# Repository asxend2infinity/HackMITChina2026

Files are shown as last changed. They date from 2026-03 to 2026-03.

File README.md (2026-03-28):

# HackMITChina2026  
**AeroVis – Helmet Integrated Heads-Up Display for Time Trial Cycling**
**Rigonomics – Real-time Riding Posture Adjustment Algorithm**

---

**Overview**

AeroVis is a helmet-integrated heads-up display (HUD) system designed for the Giro Aerohead II TT helmet, enabling cyclists to view real-time performance data without breaking their aerodynamic position.

In time trial cycling, even small posture changes can significantly impact performance. AeroVis eliminates the need to look down at a cycling computer by placing critical data directly within the rider’s field of view.

As for Rigonomics: the majority of cyclists lack professional fitting advice, and ride in over-agressive or other non-optimal postures. Rigonomics provides real-time posture adjustment advices to riders through Aerovis. By calculating critical angles used by professional fitters during fitting and bike adjustments using body-mounted gyroscopes, it can notify cyclists when their knee joints are over straight, arms are over/under streached, or leaning too forward/backward. 

This helps amature cyclists prevent injuries due to incorrect cycling postures and professional cyclists maintain efficient riding postures (improve performance).

---

**Key Features**

- Real-time display of cycling metrics (speed, power, cadence, etc.)
- Maintains full aerodynamic riding posture
- Minimal, non-intrusive UI designed for safety and clarity
- Lightweight, helmet-integrated hardware design
- Expandable architecture for future algorithm integration
- Posture alert

---

**System Architecture**

The system consists of three main components:

**Embedded System (ESP32)**  
- Handles data processing and communication  
- Receives sensor or external cycling data  
- Drives the display output  

**Display Module (HUD)**  
- Uses 2 0.91" OLED screens to reflect data onto the helmet visor  
- Optimized for visibility and minimal obstruction  

**Mechanical Integration**  
- Custom-designed housing for Giro Aerohead II TT helmet  
- Designed to intergrate the AeroVis system without altering the structure of the helmet  

**WIT Bluetooth 5.0 Giroscope module**  
- Integrated gyroscope solution with Bluetooth broadcast and built-in battery.

---

**Tech Stack**

- Microcontroller: ESP32 Dev Kit  
- WIT Bluetooth 5.0 giroscope module
- Development Environment: VSCode + PlatformIO  
- CAD Design: SolidWorks  
- Programming Language: C/C++ (embedded)  
- Prototyping Support: ChatGPT-assisted rapid development  

---

**How It Works**

Aerovis:
1. The ESP32 receives cycling data (bluetooth).  
2. Data is processed and formatted for display.  
3. The HUD renders key metrics in real time.  
4. The rider views information without needing to look down.  

Rigonomics:
1. Giro data is sent to ESP32
2. Data is processed and determinant angles are calculated
3. Alerts are displayed when rider posture crosses critical thresholds

---

**Hardware Setup**

- ESP32 & custom PCB (file included)
- OLED screens (Listed in BOM)
- Power source (Listed in BOM)  
- Custom 3D-printed mount (SolidWorks file included)  
- Giro Aerohead II MIPS

**Note:** Exact pin configuration might depend on the display module used.

---

**Getting Started**

1. Order PCB & components according to BOM, 3D print housing  
2. Clone the Repository  
3. Open in PlatformIO  

Open the project folder in VSCode  

Ensure PlatformIO extension is installed  

For pairing: Run scan_util.py and open local webpage using a browser

4. Build & Upload  

Connect ESP32 via USB  

Select correct COM port  

Upload firmware:

```bash
pio run --target upload
```

---

**Challenges**

- Maintaining visibility without obstructing rider vision  
- Integrating electronics within structural constraints  
- Ensing stable real-time data transmission  
- Angle calculation and WIT sensor connection & data decode

---

**What We’re Proud Of**

- Functional AeroVis prototype, and partially functioning Rigonomics algorithm combining hardware + embedded systems  
- Practical application in both professional and amature cycling  
- Clean integration into an existing aerodynamic helmet design  
- Strong foundation for future algorithms and extended functions

---

**Contributors**

AeroVis/Rigonomics: Pinchen LIN
Pairing Utility: Shiting HUANG

**UNRESOLVED ISSUES**

New firmware has occasional issues connecting to cycling sensors, for stable pure info display functions use aerovis_1.0_firmware.cpp in Legacy code as main.cpp; WIT motion sensors also seem to incorrectly calibrated each time rebooting, leading to inconsistent alerts and potential false alarms without manual calibration. Both issues are under investigation

**NEW FUNCTIONS**

Developed during HackMIT China 2026: New firmware adds support for Rigonomics: an algorithm designed to give rider posture adjustment alerts based on gyroscope data. Sensors can now also be added through an HTML+python utility, so users do not need to change source code when pairing new sensors. NEW PARING ROUTINE: Use scan_util to update sensor_addresses.txt, and re-upload via PIO

**FUTURE WORK**
 - Might add different UI layouts to display specialized info
 - Companion firmware site under development: settings will be adjustable without having to install PIO, VSCode .etc
 - Optical/visual enhancements

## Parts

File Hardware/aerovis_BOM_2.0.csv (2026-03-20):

No. | Quantity | Comment | Designator | Footprint | Value | Manufacturer Part | Manufacturer | Supplier Part | Supplier
1 | 4 | 100nF | C1,C10,C11,C13 | C0603 | 100nF | 0805B104K500NT | FH(风华) | C38141 | LCSC
2 | 1 | 10uF | C2 | C0603 | 10uF | CL21A106KOQNNNE | SAMSUNG(三星) | C1713 | LCSC
3 | 3 | 1uF | C3,C14,C15 | C0603 | 1uF | CL21B105KBFNNNE | SAMSUNG(三星) | C28323 | LCSC
4 | 6 | 4.7uF | C5,C42,C44,C46,C49,C50 | C0603 | 4.7uF
5 | 2 | 2.2uF | C6,C52 | C0603 | 2.2uF
6 | 2 | 10uF | C7,C8 | CAP-SMD_L3.2-W1.6-RD-C7171 | 10uF | TAJA106K016RNJ | Kyocera AVX | C7171 | LCSC
7 | 3 | 22uF | C34,C35,C36 | C0603 | 22uF
8 | 2 | 22uf | C37,C38 | C0603 | 22uf
9 | 4 | 1uF | C39,C40,C45,C47 | C0603 | 1uF
10 | 4 | 0.1uF | C41,C43,C48,C51 | C0603 | 0.1uF
11 | 2 | 10uf | C53,C54 | C0603 | 10uf | CGA0603X7R104K500JT | HRE(芯声) |  | LCSC
12 | 2 | 1N4148W | D1,D2 | SOD-123_L2.7-W1.6-LS3.7-FD |  | 1N4148W | R+O(宏嘉诚) | C7420318 | LCSC
13 | 2 | X6511WV-22H-C30D60 | H4,H5 | HDR-TH_22P-P2.54-V-M |  | X6511WV-22H-C30D60 | XKB Connectivity(中国星坤) | C725954 | LCSC
14 | 1 | 1uH | L1 | IND-SMD_L4.4-W4.2 | 1uH
15 | 1 | XL-5050RGBC-WS2812B | LED1 | LED-SMD_4P-L5.0-W5.0-BL_XL-5050RGBC |  | XL-5050RGBC-WS2812B | XINGLIGHT(成兴光) | C2843785 | LCSC
16 | 2 | SZYY0805B | LED3,LED4 | LED_0603 |  | SZYY0805B | yongyu(永裕光电) | C434433 | LCSC
17 | 1 | LED_0603-R | LED5 | LED_0603
18 | 2 | SS8050-G | Q1,Q2 | SOT-23-3_L2.9-W1.6-P1.90-LS2.8-BR |  | SS8050-G | CJ(江苏长电/长晶) | C164886 | LCSC
19 | 2 | 10kΩ | R1,R2 | R0603 | 10kΩ | 0805W8F1002T5E | UNI-ROYAL(厚声) | C17414 | LCSC
20 | 1 | 10kΩ | R3 | R0603_NEW | 10kΩ | 0805W8F1002T5E | UNI-ROYAL(厚声) | C17414 | LCSC
21 | 2 | 5.1kΩ | R5,R6 | R0603 | 5.1kΩ
22 | 2 | 1kΩ | R10,R11 | R0603 | 1kΩ | RC0805FR-071KL | YAGEO(国巨) | C95781 | LCSC
23 | 6 | 4.7K | R20,R21,R22,R24,R26,R27 | R0603 | 4.7K
24 | 2 | 560K | R23,R25 | R0603 | 560K
25 | 1 | 1K | R28 | R0603 | 1K
26 | 1 | 0.5Ω | R30 | R0603 | 0.5Ω
27 | 1 | 10K | R31 | R0603 | 10K
28 | 1 | 2Ω | R35 | R0603 | 2Ω
29 | 2 | SKRPACE010 | SW1,SW2 | KEY-SMD_4P-L4.2-W3.2-P2.20-LS4.6 |  | SKRPACE010 | ALPSALPINE(阿尔卑斯阿尔派) | C139797 | LCSC
30 | 1 | TS-1101VS-B-A-A | SW3 | SW-SMD_TS-1101VS-C-A-B |  | TS-1101VS-B-A-A | XKB Connection(中国星坤) | C561499 | LCSC
31 | 2 | Test-Point | TP1,TP2 | Test-Point-0.5mm
32 | 1 | ESP32-S3-WROOM-1-N16R8 | U1 | WIRELM-SMD_ESP32-S3-WROOM-1 |  | ESP32-S3-WROOM-1-N16R8 | ESPRESSIF(乐鑫) | C2913202 | LCSC
33 | 1 | AMS1117-3.3 | U3 | SOT-223-4_L6.5-W3.5-P2.30-LS7.0-BR |  | AMS1117-3.3 | UMW(广东友台半导体) | C347222 | LCSC
34 | 1 | CH343K | U4 | ESSOP-10_L4.9-W3.9-P1.0-LS6.0-TL-EP |  | CH343K | WCH(南京沁恒) | C5832295 | LCSC
35 | 2 | HC-FPC-0.5-14P-FH20 | U7,U8 | FPC-SMD_14P-P0.50_HC-FPC-0.5-14P-FH20 |  | HC-FPC-0.5-14P-FH20 | HC(虹成电子) | C19273929 | LCSC
36 | 1 | IP5306 | U10 | ESOP-8_L4.9-W3.9-P1.27-LS6.0-BL-EP |  | IP5306 | INJOINIC(英集芯) | C181692 | LCSC
37 | 2 | 662K | U12,U13 | SOT-23-3_L2.9-W1.3-P1.90-LS2.4-BR |  | 662K | HXY MOSFET(华轩阳电子) | C7470756 | LCSC
38 | 1 | KH-TYPE-C-16P | USB1 | USB-C-SMD_KH-TYPE-C-16P |  | KH-TYPE-C-16P | kinghelm(金航标) | C709357 | LCSC

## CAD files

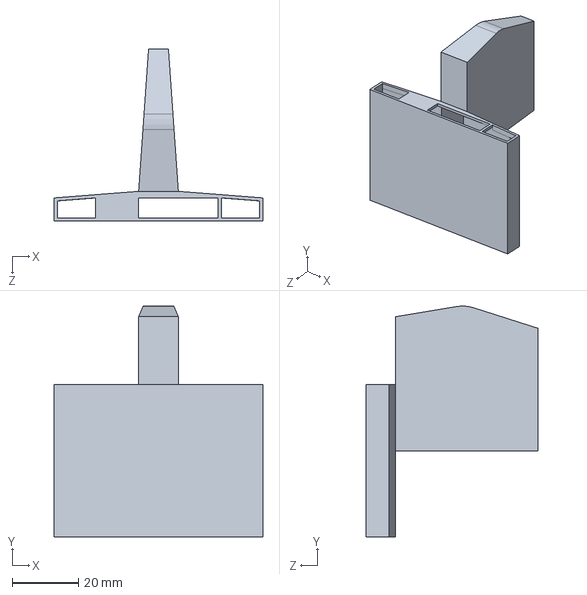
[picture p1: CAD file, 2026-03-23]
Hardware/aerovis_housing_3.0.SLDPRT
63.0 x 69.7 x 52.0 mm

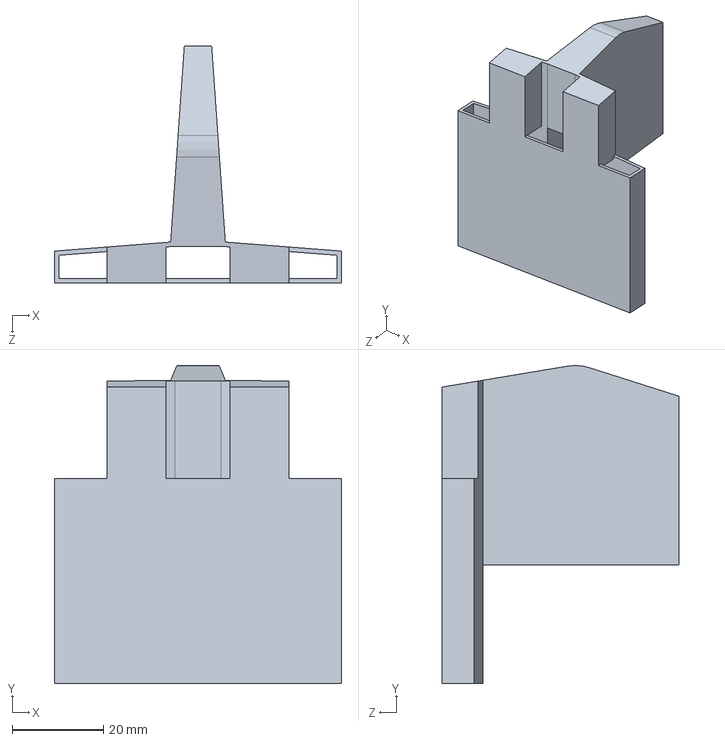
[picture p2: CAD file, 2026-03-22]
Hardware/aerovis_housing_2.0.SLDPRT
63.0 x 69.7 x 52.0 mm

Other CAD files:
Hardware/aerovis_housing_2.0.STL
Hardware/aerovis_housing_3.0.STL

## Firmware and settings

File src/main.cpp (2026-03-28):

#include <Arduino.h>
#include <Wire.h>
#include <SPIFFS.h>
#include <U8g2lib.h>
#include <NimBLEDevice.h>
#include <math.h>

// =======================================================
// OLEDs
// Screen 1: HW I2C SDA=8, SCL=9
// Screen 2: SW I2C SDA=6, SCL=7
// =======================================================
static const uint8_t OLED_ADDR_7BIT = 0x3C;

U8G2_SSD1306_128X32_UNIVISION_F_HW_I2C u8g2_screen1(U8G2_R0, U8X8_PIN_NONE);

U8G2_SSD1306_128X32_UNIVISION_F_SW_I2C u8g2_screen2(
    U8G2_R2,
    /* clock=*/7,
    /* data=*/6,
    /* reset=*/U8X8_PIN_NONE
);

// =======================================================
// Config file
// =======================================================
static const char* SENSOR_CONFIG_FILE = "/sensor_addresses.txt";

// =======================================================
// framebuffer horizontal mirror helpers
// =======================================================
static inline void mirrorHorizU8g2(U8G2 &u) {
    uint8_t *buf = u.getBufferPtr();
    const int w = u.getDisplayWidth();
    const int h = u.getDisplayHeight();
    const int pages = h / 8;

    for (int p = 0; p < pages; ++p) {
        int row = p * w;
        for (int x = 0; x < w / 2; ++x) {
            uint8_t tmp = buf[row + x];
            buf[row + x] = buf[row + (w - 1 - x)];
            buf[row + (w - 1 - x)] = tmp;
        }
    }
}

static inline void sendBufferMirrored(U8G2 &u) {
    mirrorHorizU8g2(u);
    u.sendBuffer();
    mirrorHorizU8g2(u);
}

// =======================================================
// Cycling HUD values
// =======================================================
String spdVal  = "0.0";
String distVal = "0.00";
String gearVal = "N/A";

String hrVal   = "N/A";
String cadVal  = "N/A";
String pwrVal  = "N/A";

volatile float totalDist_km = 0.0f;

unsigned long lastSpeedUpdate = 0;
unsigned long lastGearUpdate  = 0;
unsigned long lastHrUpdate    = 0;
unsigned long lastCadUpdate   = 0;
unsigned long lastPwrUpdate   = 0;

const unsigned long TIMEOUT_MS = 2000;

// =======================================================
// Cycling BLE constants/devices
// =======================================================
static const char* DI2_SVC_UUID   = "000018ef-5348-494d-414e-4f5f424c4500";
static const char* DI2_CHAR_UUID  = "00002ac1-5348-494d-414e-4f5f424c4500";

NimBLEAdvertisedDevice* di2Device = nullptr;
NimBLEClient*           di2Client = nullptr;

uint8_t lastGearPayload[32];
size_t  lastGearLen = 0;
bool    hasLastGear = false;

NimBLEAdvertisedDevice* hrDevice = nullptr;
NimBLEClient*           hrClient = nullptr;

NimBLEAdvertisedDevice* cadDevice = nullptr;
NimBLEClient*           cadClient = nullptr;

bool     hasLastCrank   = false;
uint16_t lastCrankRevs  = 0;
uint16_t lastCrankTime  = 0;

NimBLEAdvertisedDevice* spdDevice = nullptr;
NimBLEClient*           spdClient = nullptr;

bool     hasLastWheel   = false;
uint32_t lastWheelRevs  = 0;
uint16_t lastWheelTime  = 0;

NimBLEAdvertisedDevice* pmDevice = nullptr;
NimBLEClient*           pmClient = nullptr;

static const float WHEEL_CIRCUM_MM = 2105.0f;

// =======================================================
// Address targets loaded from config file
// =======================================================
String witTargetAddr[4];
String hrTargetAddr  = "";
String cadTargetAddr = "";
String spdTargetAddr = "";
String pwrTargetAddr = "";
String di2TargetAddr = "";

// =======================================================
// WIT BLE
// =======================================================
static const char* WIT_SERVICE_UUID = "0000ffe5-0000-1000-8000-00805f9a34fb";
static const char* WIT_NOTIFY_UUID  = "0000ffe4-0000-1000-8000-00805f9a34fb";

static const uint32_t WIT_DATA_TIMEOUT_MS = 2000;
static const uint32_t WIT_RETRY_PERIOD_MS = 3000;
static const uint32_t WIT_CONNECT_GAP_MS  = 300;

// =======================================================
// WIT sensor state
// Mapping:
// S1 = thigh
// S2 = calf
// S3 = arm
// S4 = back
// All use X angles
// =======================================================
struct SensorSlot {
    String targetAddr;
    NimBLEClient* client;
    float xAngle;
    float yAngle;
    uint32_t lastUpdate;
    String status;
};

SensorSlot sensors[4];

// =======================================================
// Posture parameters
// Formulas:
// knee = 180 + S2 - S1
// body = 180 - S1 + S4
// arm  = S3 - S4
// =======================================================
float KNEE_MAX_ALLOWED       = 150.0f;
float BODY_THIGH_MIN_ALLOWED = 70.0f;
float BODY_THIGH_MAX_ALLOWED = 110.0f;
float ARM_BODY_MIN_ALLOWED   = 75.0f;
float ARM_BODY_MAX_ALLOWED   = 95.0f;

// =======================================================
// Warning messages
// =======================================================
const char* MSG_KNEE_TOO_STRAIGHT = "KNEE TOO STRAIGHT";
const char* MSG_LEAN_FORWARD      = "LEAN FORWARD";
const char* MSG_LEAN_BACK         = "LEAN BACK";
const char* MSG_TUCK_ARMS_IN      = "TUCK ARMS IN";
const char* MSG_REACH_OUT         = "REACH OUT";

// =======================================================
// Posture / alert state
// =======================================================
String postureMessage = "";
String lastPostureMessage = "";
bool postureAlertActive = false;
uint32_t postureAlertLastSeenMs = 0;
static const uint32_t POSTURE_ALERT_HOLD_MS = 1200;

// Derived angles
float kneeAngle = 0.0f;
float bodyThighAngle = 0.0f;
float armBodyAngle = 0.0f;

// =======================================================
// Serial state cache
// =======================================================
String lastPrintedWitStatus[4];
bool lastPrintedDi2Connected = false;
bool lastPrintedHrConnected  = false;
bool lastPrintedCadConnected = false;
bool lastPrintedSpdConnected = false;
bool lastPrintedPwrConnected = false;
String lastPrintedAlert = "";
uint32_t lastPeriodicStatusMs = 0;

// =======================================================
// Forward declarations for WIT notify callbacks
// =======================================================
void notify0(NimBLERemoteCharacteristic*, uint8_t*, size_t, bool);
void notify1(NimBLERemoteCharacteristic*, uint8_t*, size_t, bool);
void notify2(NimBLERemoteCharacteristic*, uint8_t*, size_t, bool);
void notify3(NimBLERemoteCharacteristic*, uint8_t*, size_t, bool);

// =======================================================
// Helpers
// =======================================================
static inline bool di2Connected() { return di2Client && di2Client->isConnected(); }
static inline bool hrConnected()  { return hrClient  && hrClient->isConnected(); }
static inline bool cadConnected() { return cadClient && cadClient->isConnected(); }
static inline bool spdConnected() { return spdClient && spdClient->isConnected(); }
static inline bool pwrConnected() { return pmClient  && pmClient->isConnected(); }

static String normalizeAddr(const String& s) {
    String t = s;
    t.trim();
    t.toLowerCase();
    return t;
}

static bool witConnected(int idx) {
    return sensors[idx].client && sensors[idx].client->isConnected();
}

static bool witFresh(int idx) {
    return witConnected(idx) && (millis() - sensors[idx].lastUpdate <= WIT_DATA_TIMEOUT_MS);
}

static String decodeGear(const uint8_t* data, size_t len) {
    if (len < 6) return "N/A";
    uint8_t front = data[3];
    uint8_t rear  = data[5];
    if (front < 1 || front > 2) return "N/A";
    if (rear  < 1 || rear  > 12) return "N/A";
    return String(front) + "/" + String(rear);
}

static void printBanner(const char* title) {
    Serial.println();
    Serial.println("==================================================");
    Serial.println(title);
    Serial.println("==================================================");
}

static float wrap360(float a) {
    while (a >= 360.0f) a -= 360.0f;
    while (a < 0.0f) a += 360.0f;
    return a;
}

static float wrap180Signed(float a) {
    while (a > 180.0f) a -= 360.0f;
    while (a <= -180.0f) a += 360.0f;
    return a;
}

static float sensorAxisDeg(int idx) {
    return sensors[idx].xAngle;
}

static void setPostureAlert(const String& msg) {
    postureAlertActive = true;
    postureMessage = msg;
    lastPostureMessage = msg;
    postureAlertLastSeenMs = millis();
}

// =======================================================
// Cleanup helpers
// =======================================================
static void cleanupDi2Client() {
    if (di2Client) {
        if (di2Client->isConnected()) di2Client->disconnect();
        NimBLEDevice::deleteClient(di2Client);
        di2Client = nullptr;
    }
}

static void cleanupHRClient() {
    if (hrClient) {
        if (hrClient->isConnected()) hrClient->disconnect();
        NimBLEDevice::deleteClient(hrClient);
        hrClient = nullptr;
    }
}

static void cleanupCadClient() {
    if (cadClient) {
        if (cadClient->isConnected()) cadClient->disconnect();
        NimBLEDevice::deleteClient(cadClient);
        cadClient = nullptr;
    }
}

static void cleanupSpdClient() {
    if (spdClient) {
        if (spdClient->isConnected()) spdClient->disconnect();
        NimBLEDevice::deleteClient(spdClient);
        spdClient = nullptr;
    }
}

static void cleanupPwrClient() {
    if (pmClient) {
        if (pmClient->isConnected()) pmClient->disconnect();
        NimBLEDevice::deleteClient(pmClient);
        pmClient = nullptr;
    }
}

static void cleanupWitClient(int idx) {
    if (sensors[idx].client) {
        if (sensors[idx].client->isConnected()) sensors[idx].client->disconnect();
        NimBLEDevice::deleteClient(sensors[idx].client);
        sensors[idx].client = nullptr;
    }
}

// =======================================================
// HUD text helpers
// =======================================================
static const uint8_t X1 = 0;
static const uint8_t X2 = 44;
static const uint8_t X3 = 88;

static const uint8_t Y_HDR = 18;
static const uint8_t Y_VAL = 31;
static const uint8_t Y2_HDR = 13;
static const uint8_t Y2_VAL = 26;

static String fmtSPD()  { return spdConnected() ? (spdVal + "kph") : String("N/A"); }
static String fmtDIST() { return distVal; }
static String fmtGEAR() { return (di2Connected() && hasLastGear) ? gearVal : String("N/A"); }

static String fmtHR()   { return hrConnected()  ? hrVal  : String("N/A"); }
static String fmtCAD()  { return cadConnected() ? cadVal : String("N/A"); }
static String fmtPWR()  { return pwrConnected() ? pwrVal : String("N/A"); }

// =======================================================
// Serial reporting
// =======================================================
static void printCyclingConnStatus() {
    bool di2 = di2Connected();
    bool hr  = hrConnected();
    bool cad = cadConnected();
    bool spd = spdConnected();
    bool pwr = pwrConnected();

    if (di2 != lastPrintedDi2Connected) {
        Serial.print("[HUD] DI2: ");
        Serial.println(di2 ? "CONNECTED" : "DISCONNECTED");
        lastPrintedDi2Connected = di2;
    }
    if (hr != lastPrintedHrConnected) {
        Serial.print("[HUD] HR: ");
        Serial.println(hr ? "CONNECTED" : "DISCONNECTED");
        lastPrintedHrConnected = hr;
    }
    if (cad != lastPrintedCadConnected) {
        Serial.print("[HUD] CAD: ");
        Serial.println(cad ? "CONNECTED" : "DISCONNECTED");
        lastPrintedCadConnected = cad;
    }
    if (spd != lastPrintedSpdConnected) {
        Serial.print("[HUD] SPD: ");
        Serial.println(spd ? "CONNECTED" : "DISCONNECTED");
        lastPrintedSpdConnected = spd;
    }
    if (pwr != lastPrintedPwrConnected) {
        Serial.print("[HUD] PWR: ");
        Serial.println(pwr ? "CONNECTED" : "DISCONNECTED");
        lastPrintedPwrConnected = pwr;
    }
}

static void printWitStatusChanges() {
    for (int i = 0; i < 4; i++) {
        String nowStatus = sensors[i].status;
        if (nowStatus != lastPrintedWitStatus[i]) {
            Serial.print("[WIT] S");
            Serial.print(i + 1);
            Serial.print(": ");

            if (nowStatus == "DT") {
                Serial.println("CONNECTED");
            } else if (nowStatus == "TRY") {
                Serial.println("CONNECTING");
            } else if (nowStatus == "CF") {
                Serial.println("CONNECT FAILED");
            } else if (nowStatus == "DS") {
                Serial.println("DISCONNECTED");
            } else if (nowStatus == "WT") {
                Serial.println("CONNECTED, WAITING FOR DATA");
            } else if (nowStatus == "RDY") {
                Serial.println("READY");
            } else if (nowStatus == "FILE") {
                Serial.println("ADDRESS FILE ERROR");
            } else {
                Serial.print("STATUS=");
                Serial.println(nowStatus);
            }

            lastPrintedWitStatus[i] = nowStatus;
        }
    }
}

static void printAlertChanges() {
    String nowAlert = postureAlertActive ? postureMessage : String("NONE");
    if (nowAlert != lastPrintedAlert) {
        Serial.print("[POSTURE] ALERT -> ");
        Serial.println(nowAlert);
        lastPrintedAlert = nowAlert;
    }
}

static void printPeriodicStatusSnapshot() {
    Serial.println();
    Serial.println("----------- CONNECTION STATUS -----------");

    Serial.print("[HUD] DI2=");
    Serial.println(di2Connected() ? "CONNECTED" : "DISCONNECTED");

    Serial.print("[HUD] HR=");
    Serial.println(hrConnected() ? "CONNECTED" : "DISCONNECTED");

    Serial.print("[HUD] CAD=");
    Serial.println(cadConnected() ? "CONNECTED" : "DISCONNECTED");

    Serial.print("[HUD] SPD=");
    Serial.println(spdConnected() ? "CONNECTED" : "DISCONNECTED");

    Serial.print("[HUD] PWR=");
    Serial.println(pwrConnected() ? "CONNECTED" : "DISCONNECTED");

    for (int i = 0; i < 4; i++) {
        Serial.print("[WIT] S");
        Serial.print(i + 1);
        Serial.print("=");
        Serial.println(witConnected(i) ? "CONNECTED" : "DISCONNECTED");
    }

    for (int i = 0; i < 4; i++) {
        Serial.print("[WIT DEG] S");
        Serial.print(i + 1);
        Serial.print(" X=");
        Serial.print(sensors[i].xAngle, 2);
        Serial.print(" Y=");
        Serial.print(sensors[i].yAngle, 2);
        Serial.print(" fresh=");
        Serial.println(witFresh(i) ? "YES" : "NO");
    }

    if (witFresh(0) && witFresh(1)) {
        Serial.print("[POSTURE] kneeAngle(180+S2-S1)=");
        Serial.println(kneeAngle, 1);
    }

    if (witFresh(0) && witFresh(3)) {
        Serial.print("[POSTURE] bodyAngle(180-S1+S4)=");
        Serial.println(bodyThighAngle, 1);
    }

    if (witFresh(2) && witFresh(3)) {
        Serial.print("[POSTURE] armAngle(S3-S4)=");
        Serial.println(armBodyAngle, 1);
    }

    Serial.println("----------------------------------------");
}

// =======================================================
// Cycling notify callbacks
// =======================================================
void di2Notify(NimBLERemoteCharacteristic*, uint8_t* data, size_t len, bool) {
    if (len > sizeof(lastGearPayload)) len = sizeof(lastGearPayload);
    memcpy(lastGearPayload, data, len);
    lastGearLen = len;
    hasLastGear = true;

    gearVal = decodeGear(data, len);
    lastGearUpdate = millis();
}

void hrNotify(NimBLERemoteCharacteristic*, uint8_t* data, size_t len, bool) {
    if (len >= 2) {
        hrVal = String((int)data[1]);
        lastHrUpdate = millis();
    }
}

void cadNotify(NimBLERemoteCharacteristic*, uint8_t* data, size_t len, bool) {
    if (len < 1) return;

    uint8_t flags = data[0];
    size_t index = 1;

    bool wheelPresent = (flags & 0x01) != 0;
    bool crankPresent = (flags & 0x02) != 0;

    if (wheelPresent) {
        if (len < index + 6) return;
        index += 6;
    }
    if (!crankPresent) return;
    if (len < index + 4) return;

    uint16_t revs  = (uint16_t)data[index] | ((uint16_t)data[index + 1] << 8);
    uint16_t t1024 = (uint16_t)data[index + 2] | ((uint16_t)data[index + 3] << 8);

    if (!hasLastCrank) {
        hasLastCrank = true;
        lastCrankRevs = revs;
        lastCrankTime = t1024;
        return;
    }

    uint16_t deltaRevs = (revs >= lastCrankRevs)
        ? (revs - lastCrankRevs)
        : (uint16_t)((uint32_t)revs + 65536u - lastCrankRevs);

    uint16_t deltaTime = (t1024 >= lastCrankTime)
        ? (t1024 - lastCrankTime)
        : (uint16_t)((uint32_t)t1024 + 65536u - lastCrankTime);

    lastCrankRevs = revs;
    lastCrankTime = t1024;

    if (deltaTime == 0 || deltaRevs == 0) return;

    float dt_sec = (float)deltaTime / 1024.0f;
    float rpm = ((float)deltaRevs / dt_sec) * 60.0f;
    if (rpm < 0) rpm = 0;
    if (rpm > 250) rpm = 250;

    cadVal = String((int)(rpm + 0.5f));
    lastCadUpdate = millis();
}

void spdNotify(NimBLERemoteCharacteristic*, uint8_t* data, size_t len, bool) {
    if (len < 7) return;

    uint8_t flags = data[0];
    bool wheelPresent = (flags & 0x01) != 0;
    if (!wheelPresent) return;

    uint32_t revs =
        (uint32_t)data[1] |
        ((uint32_t)data[2] << 8) |
        ((uint32_t)data[3] << 16) |
        ((uint32_t)data[4] << 24);

    uint16_t t1024 =
        (uint16_t)data[5] |
        ((uint16_t)data[6] << 8);

    if (!hasLastWheel) {
        hasLastWheel = true;
        lastWheelRevs = revs;
        lastWheelTime = t1024;
        return;
    }

    uint32_t deltaRevs = (revs >= lastWheelRevs)
        ? (revs - lastWheelRevs)
        : ((0xFFFFFFFFu - lastWheelRevs) + 1u + revs);

    uint16_t deltaTime = (t1024 >= lastWheelTime)
        ? (t1024 - lastWheelTime)
        : (uint16_t)((uint32_t)t1024 + 65536u - lastWheelTime);

    lastWheelRevs = revs;
    lastWheelTime = t1024;

    if (deltaTime == 0 || deltaRevs == 0) return;

    float dt_sec = (float)deltaTime / 1024.0f;

    float distance_m = (float)deltaRevs * (WHEEL_CIRCUM_MM / 1000.0f);
    float speed_mps  = distance_m / dt_sec;
    float speed_kmh  = speed_mps * 3.6f;

    if (speed_kmh < 0) speed_kmh = 0;
    if (speed_kmh > 120) speed_kmh = 120;

    spdVal = String(speed_kmh, 1);

    totalDist_km += (float)deltaRevs * (WHEEL_CIRCUM_MM / 1000000.0f);
    distVal = String(totalDist_km, 2);

    lastSpeedUpdate = millis();
}

void powerNotify(NimBLERemoteCharacteristic*, uint8_t* data, size_t len, bool) {
    if (len < 4) return;
    int16_t instPower = (int16_t)((uint16_t)data[2] | ((uint16_t)data[3] << 8));
    if (instPower < 0) instPower = 0;
    if (instPower > 3000) instPower = 3000;
    pwrVal = String((int)instPower);
    lastPwrUpdate = millis();
}

// =======================================================
// WIT angle parsing
// =======================================================
static void parseAnglePacket(int idx, uint8_t* data, size_t len) {
    if (len >= 20 && data[0] == 0x55 && data[1] == 0x61) {
        int16_t xRaw = (int16_t)((data[15] << 8) | data[14]);
        int16_t yRaw = (int16_t)((data[17] << 8) | data[16]);

        sensors[idx].xAngle = xRaw / 32768.0f * 180.0f;
        sensors[idx].yAngle = yRaw / 32768.0f * 180.0f;
        sensors[idx].lastUpdate = millis();
        sensors[idx].status = "DT";
        return;
    }

    for (size_t i = 0; i + 10 < len; i++) {
        if (data[i] == 0x55 && data[i + 1] == 0x53) {
            int16_t xRaw = (int16_t)((data[i + 3] << 8) | data[i + 2]);
            int16_t yRaw = (int16_t)((data[i + 5] << 8) | data[i + 4]);

            sensors[idx].xAngle = xRaw / 32768.0f * 180.0f;
            sensors[idx].yAngle = yRaw / 32768.0f * 180.0f;
            sensors[idx].lastUpdate = millis();
            sensors[idx].status = "DT";
            return;
        }
    }
}
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
// void loop() {
//     unsigned long now = millis();

//     if (now - lastSpeedUpdate > TIMEOUT_MS) spdVal = "0.0";
//     if (now - lastGearUpdate  > TIMEOUT_MS) { hasLastGear = false; gearVal = "N/A"; }
//     if (now - lastHrUpdate    > TIMEOUT_MS) hrVal = "N/A";
//     if (now - lastCadUpdate   > TIMEOUT_MS) cadVal = "N/A";
//     if (now - lastPwrUpdate   > TIMEOUT_MS) pwrVal = "N/A";

//     if (di2Client && !di2Client->isConnected()) {
//         NimBLEDevice::deleteClient(di2Client);
//         di2Client = nullptr;
//         hasLastGear = false;
//         gearVal = "N/A";
//     }
//     if (hrClient && !hrClient->isConnected()) {
//         NimBLEDevice::deleteClient(hrClient);
//         hrClient = nullptr;
//         hrVal = "N/A";
//     }
//     if (cadClient && !cadClient->isConnected()) {
//         NimBLEDevice::deleteClient(cadClient);
//         cadClient = nullptr;
//         hasLastCrank = false;
//         cadVal = "N/A";
//     }
//     if (spdClient && !spdClient->isConnected()) {
//         NimBLEDevice::deleteClient(spdClient);
//         spdClient = nullptr;
//         hasLastWheel = false;
//         spdVal = "0.0";
//     }
//     if (pmClient && !pmClient->isConnected()) {
//         NimBLEDevice::deleteClient(pmClient);
//         pmClient = nullptr;
//         pwrVal = "N/A";
//     }

//     NimBLEScan* scan = NimBLEDevice::getScan();
//     bool needMoreDevices = (!di2Device || !hrDevice || !cadDevice || !spdDevice);
//     bool allConnected = di2Connected() && hrConnected() && cadConnected() && spdConnected();

//     if (!allConnected) {
//         if (needMoreDevices && !scan->isScanning()) {
//             scan->start(0, nullptr, false);
//         }
//     } else {
//         if (scan->isScanning()) scan->stop();
//     }

//     if (di2Device && !di2Client) connectDi2();
//     if (hrDevice  && !hrClient)  connectHR();
//     if (cadDevice && !cadClient) connectCadence();
//     if (spdDevice && !spdClient) connectSpeed();
//     if (pmDevice  && !pmClient)  connectPower();

//     drawScreen1();
//     drawScreen2();

//     delay(50);
// }

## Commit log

2026-03-20 Add PCB design and BOM
    [aerovis_BOM_2.0.csv, aerovis_housing_2.0.SLDPRT]
2026-03-22 Firmware update: display orientation
    [aerovis_housing_2.0.SLDPRT, aerovis_housing_2.0.STL]
2026-03-23 New housing
    [aerovis_housing_3.0.SLDPRT, aerovis_housing_3.0.STL]
2026-03-28 New Firmware! added rider posture adjustment alerts using body-attached giro sensors
